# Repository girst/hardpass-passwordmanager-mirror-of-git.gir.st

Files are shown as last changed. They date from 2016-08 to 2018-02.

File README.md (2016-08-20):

# Hardpass Prototype, v.2
A Raspberry Pi Zero based WiFi Enabled Hardware Password Manager, now with a PCB.

## Currently Implemented:
 - OLED (demo)
 - USB Gadgets (full)
 - USB HID send keys progam

## TODO
- OLED: Menu program
- WiFi: compile & install driver
- Button Matrix (same program as OLED)

## Install ESP driver
If you want to use the ESP8266 on the SDIO pins of the Pi, download and install the driver from Andrew Litt.
```sh
# on the pi:
git clone https://github.com/al177/esp8089.git
make && sudo make install
```

## In this repository
This repository contains:
 * USB HID progam `scan` with examples in `./send_hid`
 * OLED menu system in `./oled`, using the `ArduiPi_OLED` driver from http://hallard.me
 * Patcher and installer for `pass` in `./pass`
 * KiCAD schematic and PCB layout in `./kicad`

## Setting up
To automatically load necessary kernel modules for the OLED on boot, run as root on the Pi:
```sh
echo "i2c-dev">>/etc/modules
echo "dwc2">>/etc/modules
```

A small systemd unit file is included; place it in `/etc/systemd/system/` and modify it, so it points to `init_usb.sh`, which you can also modify to your needs. 

## License
I hereby release my work under the GNU GPLv3 where applicable. The complete license text, if not included, can be read at `https://www.gnu.org/licenses/gpl-3.0.txt`. Where the GPLv3 isn't applicable, the work is released under the Creative Commons Attribution-ShareAlike 4.0 International. 
This repository also includes the ArduiPi_OLED library from [hallard](https://github.com/hallard); see [this website](http://hallard.me/adafruit-oled-display-driver-for-pi/) for details.
and the kicad-ESP8266 library from [jdunmire](https://github.com/jdunmire/kicad-ESP8266), which is released under the Creative Commons Attribution-ShareAlike 4.0 International License.

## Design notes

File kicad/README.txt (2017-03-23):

hardpass PCB files
Copyright 2016 Tobias Girstmair, github.com/girst
Released as GPLv3, with exception to the libraries included. 

written on KiCad 4.0.3-4.0.6 on Ubuntu 16.04

Included are the following Libraries:
ESP-12 Footprint:
	https://github.com/jdunmire/kicad-ESP8266
	Copyright 2015 J.Dunmire
	Creative Commons Attribution-ShareAlike 4.0
adafruit-oled.pretty:
	extracted from adafruit's OLED breakout board. 
	https://github.com/adafruit/Adafruit-128x64-Monochrome-OLED-PCB
	Creative Commons Attribution, Share-Alike license
	(C) 2012 Adafruit Industries
RPi_Hat.pretty:
	https://github.com/xesscorp/RPi_Hat.pretty
	(C) 2015 XESS Corp.
	Mother Project (https://github.com/xesscorp/RPi_Hat_Template) MIT Licensed
hardpass.pretty:
	(C) 2015/2016 github.com/girst
	CC-BY-SA
	My own library, slightly modifying some default parts and the ESP-12E footprint from J.Dunmire. 

To the best of my knowledge, nothing but the above listed material in this folder is copyrighted. If your work has been included against the term of its license, please contact me  through the github issue tracker at http://github.com/girst/hardpass-passwordmanager/issues. 

Adafruit License Text (from https://github.com/adafruit/Adafruit-128x64-Monochrome-OLED-PCB/blob/master/README.txt): 
> This is the PCB for the Adafruit 128x64 I2C/SPI/Parallel OLED breakout board
> Format is EagleCAD schematic and board layout
> 
> For more details, check out the product page at
> 
> -----> http://www.adafruit.com/products/326
> 
> Adafruit invests time and resources providing this open source design, 
> please support Adafruit and open-source hardware by purchasing 
> products from Adafruit!
> 
> Designed by Adafruit Industries.  
> Creative Commons Attribution, Share-Alike license, check license.txt for more information
> All text above must be included in any redistribution

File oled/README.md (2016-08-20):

# Hardpass OLED menu

Some experiments in displaying menus on the Pi via an i2c OLED screen. 

This uses the ArduiPi_OLED library from http://hallard.me/adafruit-oled-display-driver-for-pi/

Please follow the link above on how to install the library on the pi. 
Compilation of all the files was done on the Pi Zero, Raspbian GNU/Linux 8 (jessie) and Kernel 4.4.6

##License
This part of the project is published as GNU GPL v3.

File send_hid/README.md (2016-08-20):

# hardpass
A hardware password manager, built around a Paspberry Pi Zero and [`pass`, the UNIX password manager](https://passwordstore.org).

This is also an entry for [Hackaday.io](https://hackaday.io)'s Pi Zero Contest. 

This repo shall also provide code for your own hid-gadgets - the code is meant to be easy to change to suit your needs. 

## Hardware
I am using a Raspberry Pi Zero, since it has USB-OTG support and a lot of GPIO to interface an OLED screen, a button matrix for input and maybe even an ESP8266 for WiFi. 
The OLED I am intending to use has an I²C interface and a screen diagonal of .96". 

## using the driver
The neccessary drivers are available only in the Raspbian 4.4 Kernel, which you can install using
```
sudo BRANCH=next rpi-update
```
You also need to activate the device tree overlay `dwc2` and load the corresponding kernel module:
```
echo "dtoverlay=dwc2" | sudo tee -a /boot/config.txt
echo "dwc2" | sudo tee -a /etc/modules
```

To use this program, you have to enable the `libcomposite` driver on the Raspberry Pi and create a USB HID gadget. 
You can use this bash script:
```
#!/bin/bash
# this is a stripped down version of https://github.com/ckuethe/usbarmory/wiki/USB-Gadgets - I don't claim any rights

modprobe libcomposite
cd /sys/kernel/config/usb_gadget/
mkdir -p g1
cd g1
echo 0x1d6b > idVendor # Linux Foundation
echo 0x0104 > idProduct # Multifunction Composite Gadget
echo 0x0100 > bcdDevice # v1.0.0
echo 0x0200 > bcdUSB # USB2
mkdir -p strings/0x409
echo "fedcba9876543210" > strings/0x409/serialnumber
echo "girst" > strings/0x409/manufacturer 
echo "Hardpass" > strings/0x409/product
N="usb0"
mkdir -p functions/hid.$N
echo 1 > functions/hid.usb0/protocol
echo 1 > functions/hid.usb0/subclass
echo 8 > functions/hid.usb0/report_length
echo -ne \\x05\\x01\\x09\\x06\\xa1\\x01\\x05\\x07\\x19\\xe0\\x29\\xe7\\x15\\x00\\x25\\x01\\x75\\x01\\x95\\x08\\x81\\x02\\x95\\x01\\x75\\x08\\x81\\x03\\x95\\x05\\x75\\x01\\x05\\x08\\x19\\x01\\x29\\x05\\x91\\x02\\x95\\x01\\x75\\x03\\x91\\x03\\x95\\x06\\x75\\x08\\x15\\x00\\x25\\x65\\x05\\x07\\x19\\x00\\x29\\x65\\x81\\x00\\xc0 > functions/hid.usb0/report_desc
C=1
mkdir -p configs/c.$C/strings/0x409
echo "Config $C: ECM network" > configs/c.$C/strings/0x409/configuration 
echo 250 > configs/c.$C/MaxPower 
ln -s functions/hid.$N configs/c.$C/
ls /sys/class/udc > UDC
```

## modifying `pass`
The version of (pass)[https://passwordstore.org] doesn't format the output as nice, so it is easier to work with. Using the `pass-installer.sh` will automatically clone from the original repository, apply the patch and install it (make sure, `patch` and `sudo` is installed). 

You can then check out `hardpass-demo.sh` to see how to supply a passphrase directly from the command line (without gpg-agent). Keep in mind, that it will show up in your history file!

## internals of this code
whenever you need to add (or remove) a new keyboard layout, the following changes have to be made:

### adding a new keyboard layout (example)
1. in `scancodes.h` add the layout to `keysym`-struct:
this identifier does not need to be used outside of scancodes.{h,c}. 
```
struct keysym {
	// ...
	struct layout de_dv; //dvorak layout
	// ...
};
```
2. the enum `kbd1` has to be ammended:
```
enum kbdl {  //keyboard layouts:
	// ...
        de_DV //de_AT-Dvorak
};
```
3. in `scancodes.c` you need to add a new column (containing more columns) to the big `keysyms[]` table:
It is suggested to explicitly name `.is_dead` and `.unicode` to avoid confusion. Also notice that `.is_dead` is part of the layout (and goes within the inner braces), while `.unicode` resides in the keysym-struct. 
if you want to add new keys, the following must be kept in mind: `toscan()` will use the nth line of the table, if n is larger than 32 (aka. will use the ascii code to look up chars). symbols not in the 7-bit ascii standard can be put on the first 32 positions as utf-8 encoded strings, although keeping [0] to the release all chars is recommended. (some text editors will convert files to older encodings - this might break things)
```
struct keysym keysyms[] = {
	//...
	{"#", {0x20, 0x02}, {0x31, 0x00}, {0x31, 0x00}, {KEY, MODIFIER}},
	{"^", {0x23, 0x02}, {0x35, 0x00}, {0x35, 0x00}, {KEY, MODIFIER, .is_dead = 1}},
	{"&", {0x24, 0x02}, {0x23, 0x02}, {0x23, 0x02}, {KEY, MODIFIER}, .unicode=OxHEX},
	//...
};
```
4. `tolay()` needs a new case to its switch statement:
This is the only place where the `layout`-idenitfier from `keysym` needs to be used. 
```
struct layout* tolay (struct keysym* s, enum kbdl layout) {
        switch (layout) {
	// ...
        case de_DV: return &(s->de_dv);
        default: return NULL;
        }
}
```
5. finally, your code must understand the new layout, represented by the `enum kbd1`-entry, `de_DV` in this example. 

## License
Copyright 2015-2016 Tobias Girstmair, own work released under the GNU GPL v3

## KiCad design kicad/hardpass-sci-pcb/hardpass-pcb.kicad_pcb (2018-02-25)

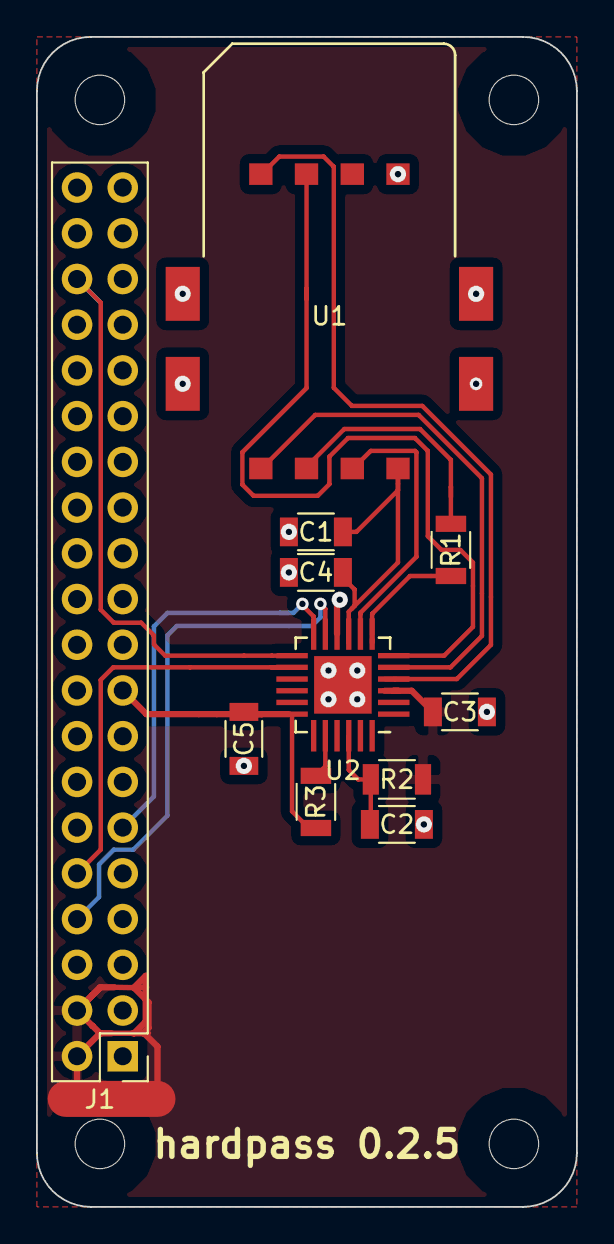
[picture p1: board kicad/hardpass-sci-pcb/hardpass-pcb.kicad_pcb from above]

Board: 2 copper layers, 30.0 x 65.0 mm, 11 parts (0 on the bottom side), 16 nets.

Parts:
C1, C2: 100n; C_1206
C3, C4, C5: 1µ; C_1206
J1: Raspberry_Pi_2_3; Pin_Header_Straight_2x20_Pitch2.54mm_centered
R1: 43; R_1206
R2: 100K; R_1206
R3: 1M; R_1206
U1: ISO7816; CAF99-08153-S132
U2: SEC1210; QFN-24-1EP_5x5mm_Pitch0.65mm_HandSoldering

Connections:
+3V3: C5.1, J1.1, J1.17, R3.1, U2.18
+5V: C3.1, J1.2, J1.4, R2.2, U2.3
CARD_CTS: J1.11, U2.12
CARD_RTS: J1.36, U2.13
CARD_RX: J1.8, U2.11
CARD_TX: J1.10, U2.14
GND: C1.2, C2.1, C3.2, C4.2, C5.2, J1.6, J1.9, J1.14, J1.20, J1.25, J1.30, J1.34, J1.39, U1.5, U2.10, U2.25
unnamed: C1.1, C4.1, U1.1, U2.9
unnamed: C2.2, R2.1, U2.22
unnamed: R3.2, U2.20
unnamed: R1.1, U2.7
unnamed: R1.2, U1.3
unnamed: U1.2, U2.8
unnamed: U1.4, U2.5
unnamed: U1.7, U2.6
unnamed: U1.8, U2.4

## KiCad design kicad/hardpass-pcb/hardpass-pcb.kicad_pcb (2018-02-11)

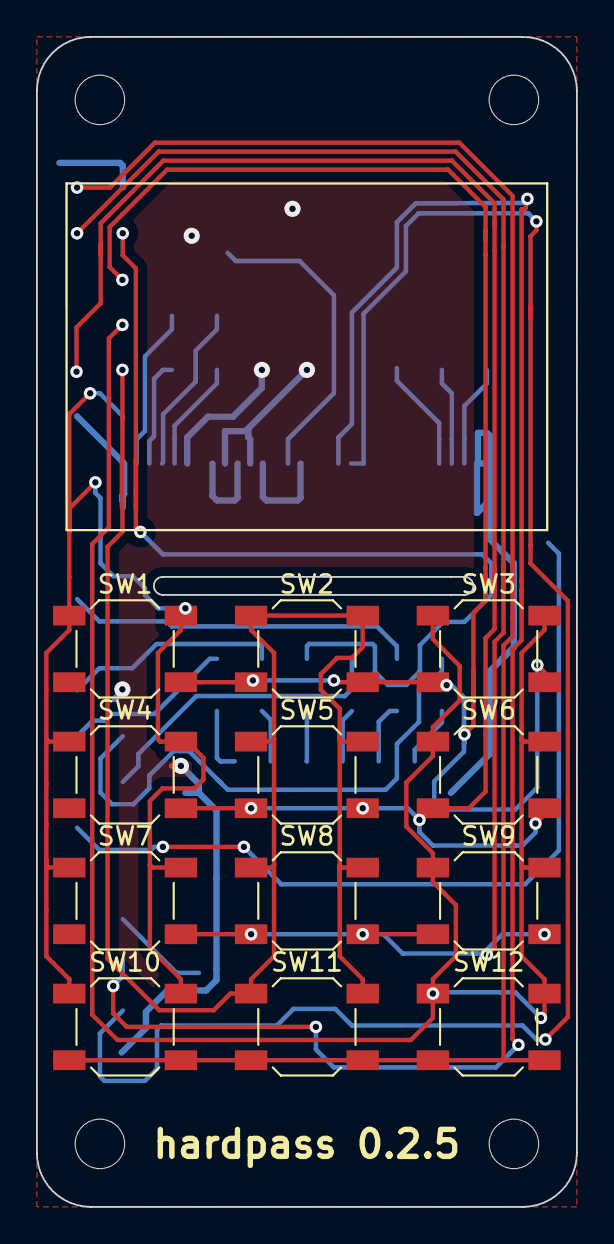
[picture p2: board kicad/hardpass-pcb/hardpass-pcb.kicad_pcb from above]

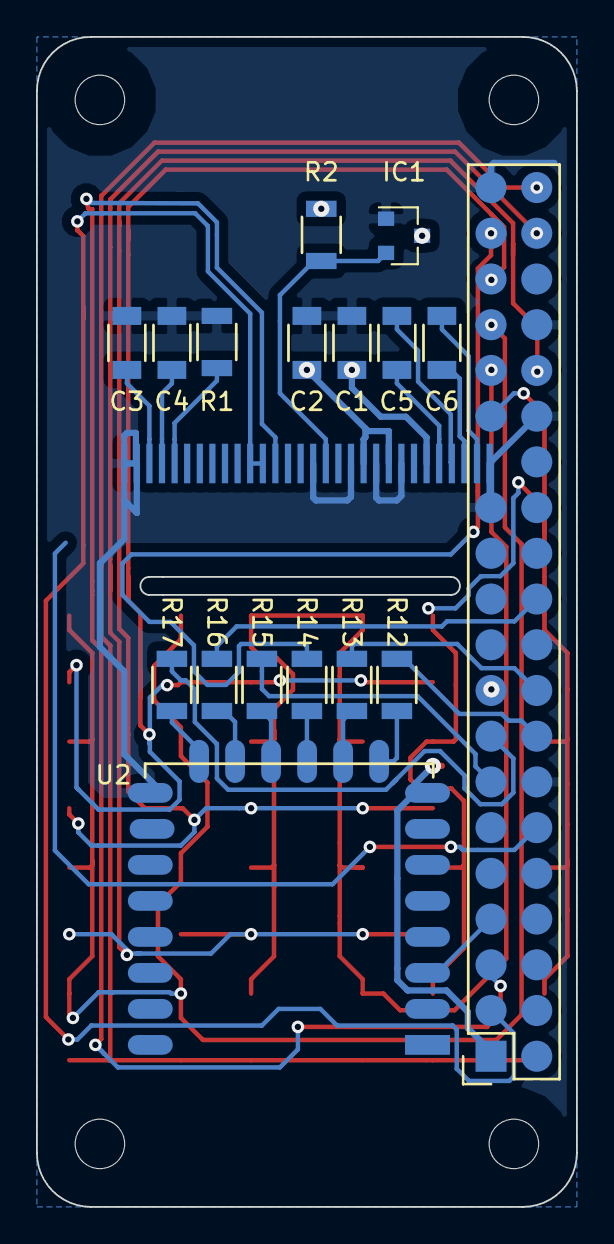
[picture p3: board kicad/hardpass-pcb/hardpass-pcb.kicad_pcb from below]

Board: 2 copper layers, 30.0 x 65.0 mm, 30 parts (17 on the bottom side), 32 nets.

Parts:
C1, C2, C4, C5, C6: 2.2µF; C_1206
C3: 10µF; C_1206
IC1: APX803; SOT-23
J1: Raspberry_Pi_2_3; Pin_Header_Mirrored-NoHoles_centered_2x20
P2: OLED_I2C; UG-2864HSWEG01_0.96IN_WRAPAROUND
R1: 390k; R_1206
R2: 10k; R_1206
R12, R13, R14, R15, R16, R17: 33; R_1206
SW1: 1; SW_SPST_SKQG
SW2: 2; SW_SPST_SKQG
SW3: 3; SW_SPST_SKQG
SW4: 4; SW_SPST_SKQG
SW5: 5; SW_SPST_SKQG
SW6: 6; SW_SPST_SKQG
SW7: 7; SW_SPST_SKQG
SW8: 8; SW_SPST_SKQG
SW9: 9; SW_SPST_SKQG
SW10: C/UP; SW_SPST_SKQG
SW11: 0/OK; SW_SPST_SKQG
SW12: OK/DN; SW_SPST_SKQG
U2: ESP-12E; ESP-12E_smd

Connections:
+3V3: C1.2, C2.2, IC1.3, J1.1, J1.17, P2.6, P2.9, P2.11, R2.1, U2.8
COL_1: J1.29, SW1.1, SW4.1, SW7.1, SW10.1
COL_2: J1.31, SW2.1, SW5.1, SW8.1, SW11.1
COL_3: J1.33, SW3.1, SW6.1, SW9.1, SW12.1
ESP_CHPD: J1.7, U2.3
ESP_CLK: J1.15, R17.2
GND: C1.1, C2.1, C3.2, C4.2, IC1.1, J1.14, J1.20, J1.25, J1.30, J1.34, J1.39, P2.1, P2.8, P2.10, P2.12, P2.15, P2.29, P2.30, R1.2, U2.15
unnamed: C3.1, P2.28
unnamed: C4.1, P2.27
unnamed: C5.1, P2.4
unnamed: C5.2, P2.5
unnamed: C6.1, P2.2
unnamed: C6.2, P2.3
unnamed: P2.26, R1.1
unnamed: R12.1, U2.9
unnamed: R13.1, U2.10
unnamed: R14.1, U2.11
unnamed: R15.1, U2.12
unnamed: R16.1, U2.13
unnamed: R17.1, U2.14
OLED_RST: IC1.2, P2.14, R2.2
OLED_SCL: J1.5, P2.18
OLED_SDA: J1.3, P2.19, P2.20
ROW_1: J1.35, SW1.2, SW2.2, SW3.2
ROW_2: J1.32, SW4.2, SW5.2, SW6.2
ROW_3: J1.38, SW7.2, SW8.2, SW9.2
ROW_4: J1.40, SW10.2, SW11.2, SW12.2
SD_CMD: J1.16, R12.2
SD_D0: J1.18, R13.2
SD_D1: J1.22, R16.2
SD_D2: J1.37, R14.2
SD_D3: J1.13, R15.2

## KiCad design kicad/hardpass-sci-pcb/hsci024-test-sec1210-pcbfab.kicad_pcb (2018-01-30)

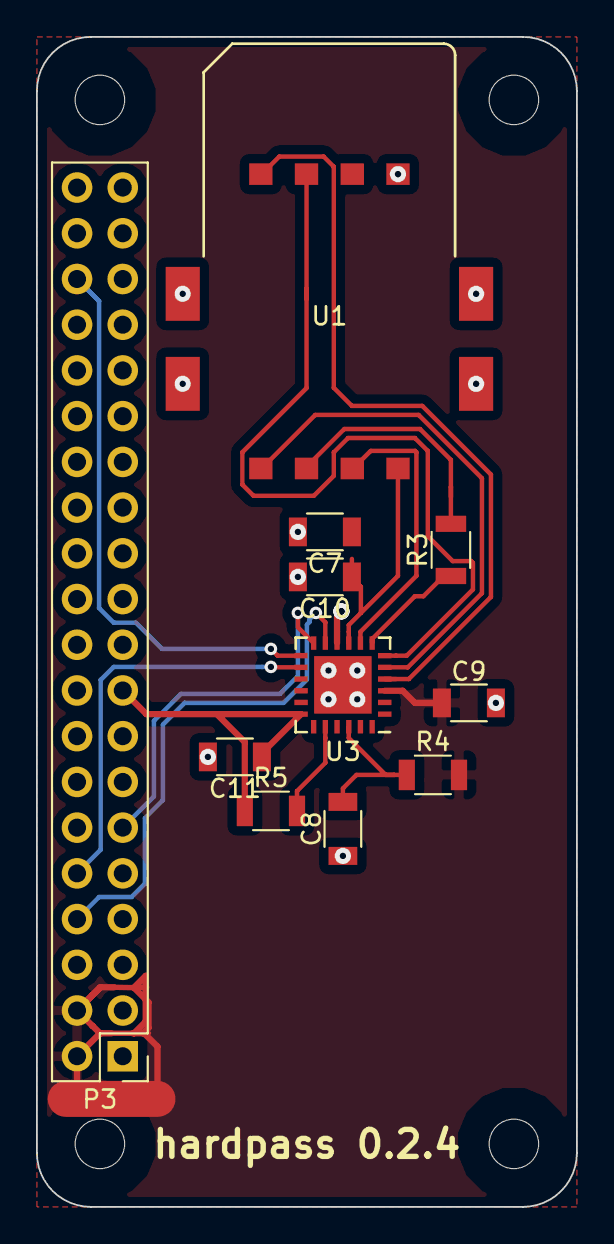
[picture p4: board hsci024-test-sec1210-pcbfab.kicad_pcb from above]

Board: 2 copper layers, 30.0 x 65.0 mm, 11 parts (0 on the bottom side), 16 nets.

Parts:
C7, C8: 100n; C_1206
C9, C10, C11: 1µ; C_1206
P3: Pi_Zero; Pin_Header_Straight_2x20_Pitch2.54mm_centered
R3: 43; R_1206
R4: 100K; R_1206
R5: 1M; R_1206
U1: ISO7816; CAF99-08153-S132
U3: SEC1210; QFN-24-1EP_5x5mm_Pitch0.65mm

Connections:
+3V3: C11.1, P3.1, P3.17, R5.1, U3.18
+5V: C9.1, P3.2, P3.4, R4.2, U3.3
CARD_CTS: P3.11, U3.12
CARD_RTS: P3.36, U3.13
CARD_RX: P3.8, U3.11
CARD_TX: P3.10, U3.14
GND: C7.2, C8.1, C9.2, C10.2, C11.2, P3.6, P3.9, P3.14, P3.20, P3.25, P3.30, P3.34, P3.39, U1.5, U3.10, U3.25
unnamed: C8.2, R4.1, U3.22
unnamed: C7.1, C10.1, U1.1, U3.9
unnamed: R5.2, U3.20
unnamed: R3.1, U3.7
unnamed: R3.2, U1.3
unnamed: U1.2, U3.8
unnamed: U1.4, U3.5
unnamed: U1.7, U3.6
unnamed: U1.8, U3.4

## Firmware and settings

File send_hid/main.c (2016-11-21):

/*
(C) 2016 Tobias Girstmair, released under the GNU GPL

description: sends a sequence of keystrokes provided from stdin to the hid
device. 
stops typing at: control characters (including newline), chars not in table, EOF
parameters:
	device file (e.g. /dev/hidg0)
	keyboard layout (1=en_us, 2=de_at, 3=de_at-nodeadkeys)
	unicode method: 1=gtk_holddown, 2=gtk_spaceend, 3=windows
*/
#include <stdio.h>
#include <stdlib.h>
#include <string.h>
#include "scancodes.h"

#define TEXT_LEN 256 //max length of piped text
enum params {//argv-indices:
	P_EXE, //executable name
	P_DEV, //device file
	P_LAY, //layout
	P_UNI, //unicode method
	NUM_P  //number of parameters
};
enum uni_m {//unicode methods:
	SKIP, //ignore any keys not on the layout
	GTK_HOLD, //hold ctrl and shift while entering hex values
	GTK_SPACE, //end hex sequence with spacebar
	WINDOWS //use alt+numpad
};
enum errors {
	ERR_SUCCESS, //no error
	ERR_ARGCOUNT, //wrong number of arguments
	ERR_SYMBOL, //symbol not in look up table
	ERR_LAYOUT, //parameter P_LAY does not contain a correct keyboard layout
	ERR_LAZY //i haven't done this
};

void send_key (FILE* hid_dev, unsigned short key, unsigned short mod);
enum errors send_unicode (FILE* hid_dev, unsigned int unicode, enum uni_m method, enum kbdl layout);

int main (int argc, char** argv) {
	if (argc != NUM_P) {
		fprintf (stderr, "Usage: %s <device file> <layout> <unicode>\n", argv[P_EXE]);
		fprintf (stderr, "Takes string to type from stdin\n");
		fprintf (stderr, "<device file>:\ton the Raspberry Pi usually /dev/hidg0\n");
		fprintf (stderr, "<layout>:\n\t%d\t%s\n\t%d\t%s\n\t%d\t%s\n", 
			en_US, "en_US", 
			de_AT, "de_AT (w/ dead keys)", 
			de_ND, "de_AT-nodeadkeys");
		fprintf (stderr, "<unicode>:\n\t%d\t%s\n\t%d\t%s\n\t%d\t%s\n\t%d\t%s\n", 
			SKIP, "skip over unicode characters", 
			GTK_HOLD, "X11 Holddown: CTRL+SHIFT+[u, hex]",
			GTK_SPACE, "X11 Space: CTRL+SHIFT+u, hex, SPACE",
			WINDOWS, "Windows: Alt+[Numpad]");
		return ERR_ARGCOUNT;
	}
	FILE* hid_dev = fopen (argv[P_DEV], "w");
	char in_string[TEXT_LEN];
	fgets(in_string, TEXT_LEN, stdin);
	for (int i = 0; i < strlen (in_string); i++) {
/*		if (in_string[i] < 32) {
			if (in_string[i] != '\n') fprintf (stderr, "Cannot print control characters!\n(Is there a newline at the end of your string?\n");
			return ERR_SYMBOL;
		}
*/
		char tmp[UTF8_MAX_LENGTH] = {in_string[i], in_string[i+1], in_string[i+2], '\0'};
		//TODO: replace by something less stupid
		if (in_string[i] < 128) { // not multi byte
			tmp[1] = '\0';
		} else { // is multi byte
			if (in_string[i] < 0xe0) {
			i++; //skip next thing
			tmp[2] = 0;
			} else {
			i+=2; //WARN: fails on utf8 > 3 byte
			}
		}

		struct keysym* s = toscan (tmp);
		if (s == NULL) {
			fprintf (stderr, "Key Symbol not found.\n");
fclose (hid_dev);
			return ERR_SYMBOL;
		}
		struct layout* l = tolay (s, atoi (argv[P_LAY]));
		if (l == NULL) {
			fprintf (stderr, "Unrecognised keyboard layout.\n");
fclose (hid_dev);
			return ERR_LAYOUT;
		}
		if (l->key != 0x00) {
			send_key(hid_dev, l->key, l->mod);
			send_key(hid_dev, '\0', '\0'); //release all keys
			if (l->is_dead) {
				//dead keys need to be pressed twice to show up
				send_key(hid_dev, l->key, l->mod);
				send_key(hid_dev, '\0', '\0'); //release all keys
			}
		} else {
			//key does not exist in this layout, use unicode method
			//fprintf (stderr, "Warning: Key '%s'(0x%x) not in this layout!\n", s->sym, s->unicode);
			send_unicode (hid_dev, s->unicode, atoi (argv[P_UNI]), atoi(argv[P_LAY]));
		}
	}
	fclose (hid_dev);

	return ERR_SUCCESS;
}

void send_key (FILE* hid_dev, unsigned short key, unsigned short mod) {
	fprintf (hid_dev, "%c%c%c%c%c%c%c%c", mod, '\0', key, '\0', '\0', '\0', '\0', '\0');
}

enum errors send_unicode (FILE* hid_dev, unsigned int unicode, enum uni_m method, enum kbdl layout) {
	char buf[10];
	struct keysym* s;
	struct layout* l;

	if (unicode == 0x00) {
		fprintf (stderr, "Symbol not in lookup table!\n");
		return ERR_SYMBOL;
	}

	switch (method) {
	case SKIP:
		break;
	case GTK_HOLD:
		sprintf (buf, "%x", unicode);
		s = toscan ("u");
		l = tolay (s, layout);
		send_key (hid_dev, l->key, MOD_LCTRL | MOD_LSHIFT);
		for (int i = 0; i < strlen (buf); i++) {
			s = toscan ((char[2]){buf[i], '\0'});
			l = tolay (s, layout);
			send_key (hid_dev, l->key, MOD_LCTRL | MOD_LSHIFT);
		}
		send_key (hid_dev, '\0', '\0');
		break;
	case GTK_SPACE:
		sprintf (buf, "%x ", unicode);
		s = toscan ("u");
		l = tolay (s, layout);
		send_key (hid_dev, l->key, MOD_LCTRL | MOD_LSHIFT);
		for (int i = 0; i < strlen (buf); i++) {
			s = toscan ((char[2]){buf[i], '\0'});
			l = tolay (s, layout);
			send_key (hid_dev, l->key, MOD_NONE);
		}
		send_key (hid_dev, '\0', '\0');
		break;
	case WINDOWS:
		fprintf (stderr, "windows method not implemented!\n");
		return ERR_LAZY;
	default:
		fprintf (stderr, "unknown unicode method!\n");
		return ERR_LAYOUT; //TODO: better error code
	}
	return ERR_SUCCESS;
}

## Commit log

2016-08-20 Code import into new repository (long overdue)
    [hardpass-esp12e.kicad_pcb, hardpass-pcb.kicad_pcb, hardpass-pcb.sch]
2016-09-12 Actually use the device argument
    see https://github.com/girst/hardpass-sendHID/pull/2/files
2016-11-21 added reset circuit to oled
    [hardpass-pcb.kicad_pcb]
2016-11-21 removed spi labels from oled (won#t happen anyways)
    [hardpass-pcb.sch]
2016-11-21 removed a few footprint labels for cleaner look
    [hardpass-pcb.sch]
2017-01-07 re-done pcb for 30 pin oled
    pcb was completely redone, fixing header-misalignment (hopefully) and removing ugly silk screen from the front
    [hardpass-pcb.kicad_pcb, hardpass-pcb.sch, old-hardpass-pcb.kicad_pcb]
2017-01-07 added logo
    [hardpass-pcb.kicad_pcb]
2017-01-18 add tda8029 footprint
    [hardpass-pcb.kicad_pcb]
2017-01-18 wired up tda8029
    [hardpass-pcb.sch]
2017-01-18 moving stuff around the tda8029
    rotated schema back to normal
    [hardpass-pcb.sch]
2017-01-18 added note to schema
    possible driver to use with the tda
    [hardpass-pcb.sch]
2017-01-19 created footprint for sim slot
    will use a linkconn sim connector, available from aliexpress using the term 'samsung note n7000 i9000 9003 sim connector'
    [hardpass-pcb.sch]
2017-01-19 added pin header for second board
    [hardpass-pcb.sch]
2017-01-19 routed 2nd board
    not finished, but a start
    [hardpass-pcb.kicad_pcb, hardpass-pcb.sch]
2017-01-21 fixed bug (shdn_N), removed caps
    according to data sheet, shdn_n needs to be high to activate card (page43)
    2 bypass caps have been removed according to page 8 of AN00046
    [hardpass-pcb.kicad_pcb, hardpass-pcb.sch]
2017-01-21 board design work
    [_saved_hardpass-pcb.sch, hardpass-pcb.kicad_pcb]
2017-03-11 cleanup, but accidentally deleted smartcard-pcb
    [hardpass-pcb.kicad_pcb, hardpass-pcb.sch]
2017-03-11 Revert "cleanup, but accidentally deleted smartcard-pcb"
    This reverts commit a86da60cfe61b4d59f182c2c3fe14bc6cea5c2cc.
    [hardpass-pcb.kicad_pcb, hardpass-pcb.sch]
2017-03-11 change crystal to smd
    also added GND-netname to sim-mech-pads from within pcbnew. this will
    sadly automatically be reverted everytime you load the netlist, as i
    haven't bothered updating the footprint itself (then i'd have to add it
    in the schematic too, and that part is already pretty cluttered)
    [hardpass-pcb.kicad_pcb, hardpass-pcb.sch]
2017-03-11 added markers around potentially unnecessary capacitors
    keeping them in the schema until testing on physical board has been
    done.
    [hardpass-pcb.sch]
2017-03-17 update README to include adafruit license
    forgive me, for i have sinned by not including the adafruit license text
    for their awesome sd1306 footprint. the footprint was extracted from the
    eagle library with kicad's library editor.
2017-03-19 created 3d model for sim holder
    accuracy is questionable, but i call it good enough for a first try.
    [linkconn_sim_holder.fcstd, sim_holder.stl]
2017-03-19 add 3d model to pcb
    used absolute filepath because kicad won't show it otherwise. bummer.
2017-03-19 cleanup tracks around xtal
    [hardpass-pcb.kicad_pcb]
2017-03-23 fixed multiple things, add gnu logo
    fixed:
    * mounting holes now non plated
    * fixed a few wires here and there
    * added a gnu/gpl logo for testing graphics
    [hardpass-pcb.kicad_pcb]
2017-06-10 reset circuit redesign WARN: multiple defined@once
    [hardpass-pcb.sch]
2017-06-10 remove other non-ic reset methods
    [hardpass-pcb.sch]
2017-07-22 reset circuit works; cleanup on it
    [hardpass-pcb.kicad_pcb, hardpass-pcb.sch]
2017-07-23 increase version number on pcb
2017-07-23 minimal cleanup on pcb
    [hardpass-pcb.kicad_pcb]
2017-08-25 fix missing trace on hardpass-scm
    also removes a small not-connected-to-anything trace under the oled.
    [hardpass-pcb.kicad_pcb]
2017-08-30 PCB cleanup silkscreen, fab-layer
    on the fabrication layer all the values of the small components like
    resistors and capactiors are now inside the footprints for easier
    referencing.
    the silk screen markings have been cleaned up as well, most notably
    moved them off the footprints on hardpass, and aligned them neatly on
    hardpass-sci, where some of the automatically placed ones were even on
    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
    [hardpass-pcb.kicad_pcb]
2017-09-16 use relative paths for custom 3d models
    i tried to do this before, but pcbnew just moved up the directory tree until it hit root (using ../), then used the absolute path again.
    kicad.info forums suggested to use ${KIPRJMOD}, which works.
    [hardpass-pcb.kicad_pcb]
2017-09-16 add model for ssd1306
    i finally managed to convince joe su to relicense monitor_tinyscreen under a
    free license. his model has now been included in hardpass' kicad project, and
    he is credited inhardpass.3dshapes/README.md
    [hardpass-pcb.kicad_pcb]
2017-09-16 ssd1306: 3d model flatflex; correct thickness
    also includes blender model and wings-file (for coloring)
2018-01-28 switch smartcard chip to microchip SEC1210
    [hardpass-pcb.kicad_pcb, hardpass-pcb.sch]
2018-01-30 small fixes
    schematic: add either-or text to card-led
    pcb: connect c10 to card-pin1
    [hardpass-pcb.kicad_pcb, hardpass-pcb.sch, hsci024-test-sec1210-pcbfab.kicad_pcb]
2018-02-10 seperate hardpass and hardpass-sci kicad projects
    [hardpass-pcb.kicad_pcb, hardpass-pcb.sch]
2018-02-10 seperate hardpass-frontend from hardpass-sci, II
    (I) was sci
    (II) is frontend
    also general cleanup and version bump to 0.2.5
    [hardpass-pcb.kicad_pcb]
2018-02-10 redesign frontend with 5.2mm tact switches
    reason being, those are flat enough so they don't protrude above the
    oled. I'm thinking about putting a lasercut sheet of plexiglass as a
    protecting case in front
    [hardpass-pcb.kicad_pcb, hardpass-pcb.sch]
2018-02-10 use realistic colors for 5.2mm tact switches
    as it turns out, step files are plain text -- so search and replace can
    be used to modify colors reliably
    search for colors:
    grep COLOUR_RGB SKQGAF-realcolors.STEP|awk -F= '{print $2}'|sort|uniq -c
    replace them with
    sed -i "s/$OLDCOLOR/$NEWCOLOR/" SKQGAF-realcolors.STEP
2018-02-11 cleanup on the frontend-pcb
    [hardpass-pcb.kicad_pcb, hardpass-pcb.sch]
2018-02-11 cleanup frontend-pcb some more, shutdown-button-note
    [hardpass-pcb.kicad_pcb]
2018-02-11 more shutdown-button routing
    [hardpass-pcb.kicad_pcb]
2018-02-25 change sec1210 footprint to handsoldering
    should ease qfn soldering by hand due to the elongated pads. this also
    required moveing some traces out of the way on the pcb.
    [hardpass-pcb.kicad_pcb, hardpass-pcb.sch]
